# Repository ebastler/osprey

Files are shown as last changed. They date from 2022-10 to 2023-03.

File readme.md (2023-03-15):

# Osprey

The Osprey is a column staggered 40% wireless ergonomic keyboard. PCB and 3D-printable case are both open source (CERN OHL Permissive), and so is the software (MIT) as it is designed to run the [ZMK firmware](https://github.com/zmkfirmware/zmk).

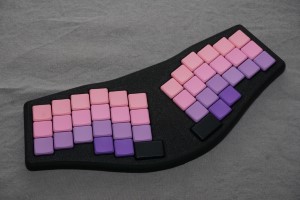
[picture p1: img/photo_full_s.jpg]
Entire board
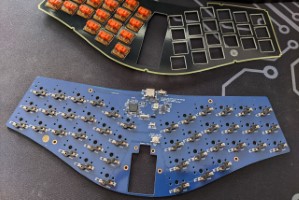
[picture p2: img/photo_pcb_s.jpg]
Entire PCB
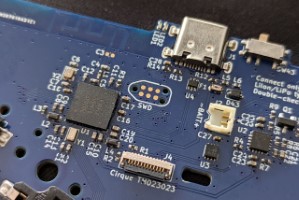
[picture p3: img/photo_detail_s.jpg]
PCB detail
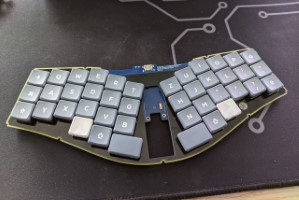
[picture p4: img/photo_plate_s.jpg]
Plate with caps and PCB
     

The board was designed to be an elegant and sleek unibody keyboard, without sacrificing typing comfort or portability. While the enclosure has raised edges to hide the keyswitches for a more refined look, it is still as slim as possible with Choc v1 switches, leading to a total thickness of about 16 mm from bottom to keycap top, if used with MBK keycaps.

The PCB is "floating" inside the case and the switches are held in-place by a 1.2 mm FR4 plate, which is sandwiched between case top and bottom half.

## Hardware
The Rev A is the first board in the Osprey family, using an nRF52840 chip, running in full DC-DC mode for highest possible battery life. A Texas Instruments BQ24075 battery management chip ensures reliable charging, while a MAX17048 fuel gauge allows for accurate battery status measurements which are communicated to your PC via Bluetooth.

The PCB is designed for Kailh Choc v1, which can be hot-swapped, and does not need any stabilizers - the largest key is 1.5u for the thumbs.

The PCB has connectors to connect either an Alps RKJXU1210006 (also known as PSP-3000 thumbstick) or a Cirque TM023023 touchpad - Both are not yet supported firmware-side and by the case design, but the PCB is ready for either.

You will also need a 502030 battery (20 x 30 x 5 mm), which usually come between 200 and 250 mAh of capacity. The board uses a JST ACH low profile connector, so you will need either a JST ACH or Molex Pico EZmate cable to crimp/solder to the battery to connect it to the PCB - please be wary of the pinout and do not connect a wrong polarity battery, as that would destroy the PCB.

It was prototyped at PCBway and turned out great. Other manufacturers should be able to make sense of the files I attached and solder these PCBs, but it is untested so order there at your own risk. 

### Files needed for ordering the PCB:

- Order in 1.6mm FR4, ENIG finish
- [Gerber Files](osprey_rev_a/fab/osprey_rev_a-GERBER.zip)
- [BOM file](osprey_rev_a/fab/osprey_rev_a_BOM.xlsx)
- [POS file](osprey_rev_a/fab/osprey_rev_a-bottom-POS.csv)

Top side  Bottom side

### Files needed for ordering the plate:

- Order in 1.2mm FR4, finish does not matter
- [Gerber Files](osprey_plate/fab/osprey_plate.zip)

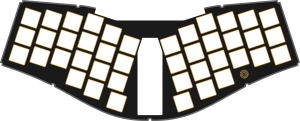
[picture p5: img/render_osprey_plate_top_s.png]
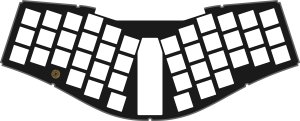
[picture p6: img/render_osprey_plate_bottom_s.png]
Bottom side
  

## Enclosure
I have attached step and 3mf files of the latest enclosure prototype - the case is still work in progress, as it lacks capability of adding thumbstick or touchpad. It is, however, tested and works fine for regular keyboard use. The enclosure is designed for [Ruthex M2 threaded inserts](https://www.ruthex.de/products/ruthex-gewindeeinsatz-m2-70-stuck-rx-m2x4-messing-gewindebuchsen) and M2x8 cylindrical head screws with flat TORX head (ISO 14580) - 9 piece each. 7 3M rubber bumpons with 7.9 mm diameter are used as feet. Other inserts, screws and bumpons may work but are untested.
- [Top enclosure, step](osprey_enclosure/osprey_enclosure_top.step)
- [Bottom enclosure, step](osprey_enclosure/osprey_enclosure_bot.step)
- [Top enclosure, 3mf](osprey_enclosure/osprey_enclosure_top.3mf)
- [Bottom enclosure, 3mf](osprey_enclosure/osprey_enclosure_bot.3mf)

Front side  Rear side

## Software
As mentioned earlier, the board is designed to run the open source ZMK firmware. My current firmware config can be found in my [ZMK config](https://github.com/ebastler/zmk-config/tree/osprey-a/config/boards/arm/osprey) repository. Since the MAX17048 needs a not-yet-merged pull request (and some manual fixes applied to it) it points towards a custom branch on a ZMK fork, not towards the official repository. This board can not (yet) be built from ZMK main branch. The current version is broken and softbricks the board!

I am using an Adafruit Bootloader, a readily compiled one can be downloaded from the [github actions in my fork of their repository](https://github.com/ebastler/Adafruit_nRF52_Bootloader/actions). This needs to be flashed with a J-Link, Black Magic Probe or modified STlink v2 using a TC2030 flashing header.

## Thanks
 - [PCBWay](https://www.pcbway.com/) for the top notch quality sponsored PCBs - couldn't have done it without you!
 - [propagandalf](https://github.com/propagandalf1) for the 3D printed cases - thank you very much!

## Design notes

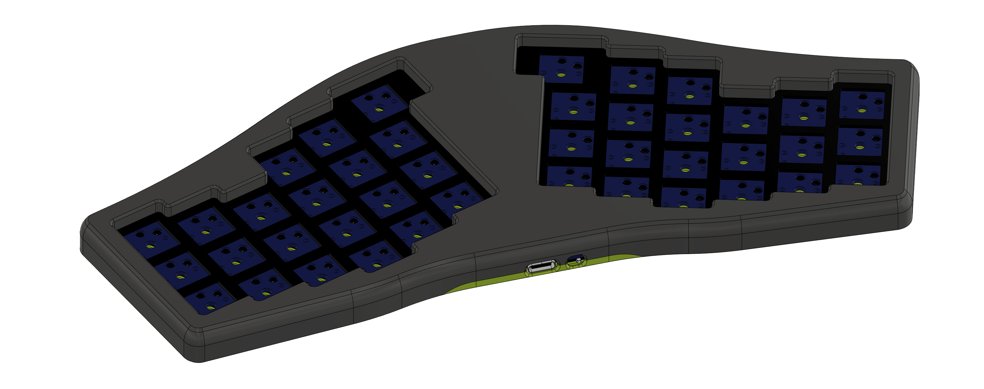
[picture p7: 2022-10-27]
img/render_osprey_case2.png

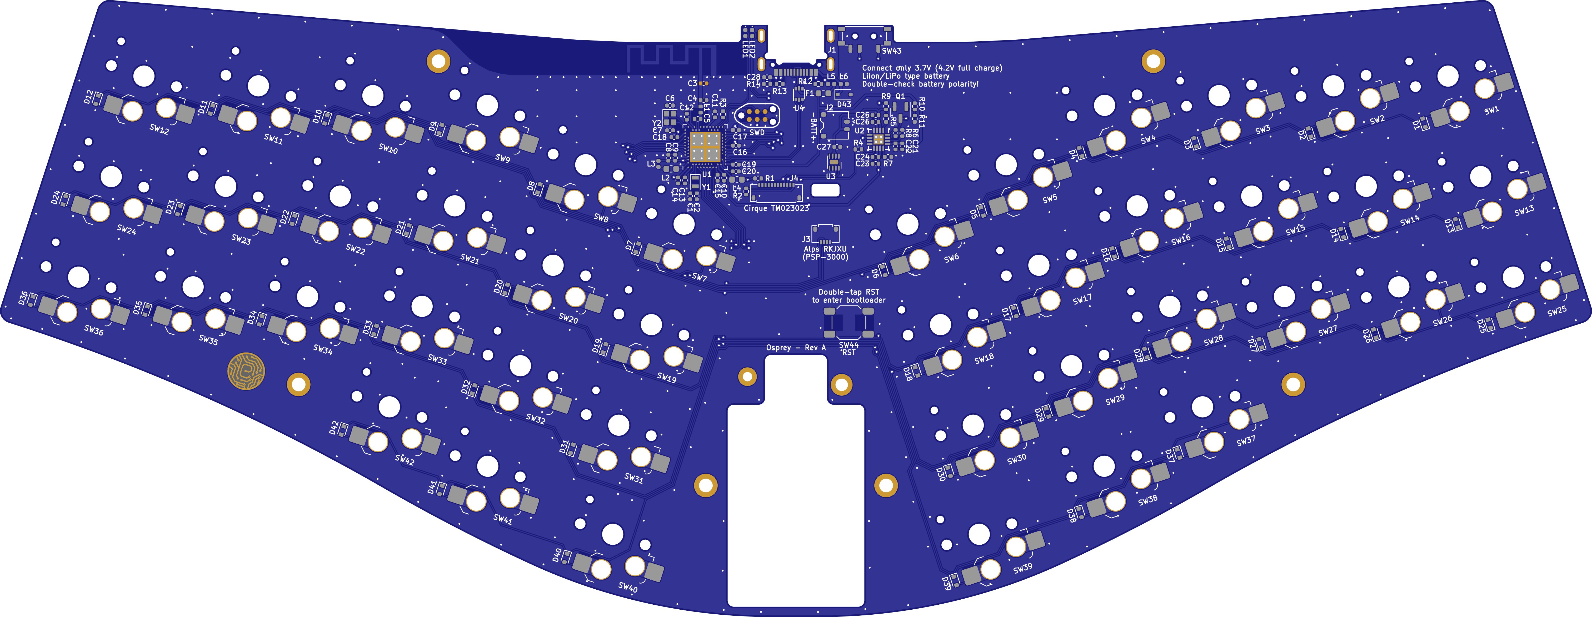
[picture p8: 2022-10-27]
img/render_osprey_rev_a_bottom.png

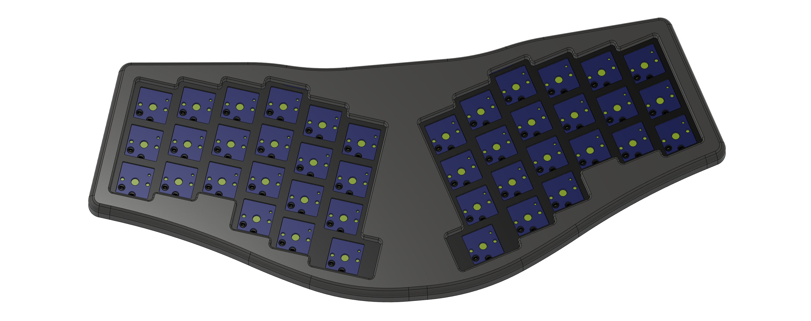
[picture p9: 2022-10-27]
img/render_osprey_case1.png

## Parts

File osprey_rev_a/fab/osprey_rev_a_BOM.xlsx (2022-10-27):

Item # | Designator | Qty | Value | Type/Description | Footprint | Manufacturer | Mfg Part # | Notes | Assembly
1 | C1, C2, C6, C7 | 4 | 12 pF | Ceramic capacitor, NP0, ±2% | 0402 |  |  | Manufacturer does not matter | SMD
2 | C3 | 0 | Not mounted | Not mounted | Not mounted |  |  | Not mounted | Not mounted
3 | C4 | 1 | 0.5 pF | Ceramic capacitor, NP0, ±10% | 0402 |  |  | Manufacturer does not matter | SMD
4 | C5 | 1 | 0.8 pF | Ceramic capacitor, NP0, ±10% | 0402 |  |  | Manufacturer does not matter | SMD
5 | C8, C14, C22, C24, C26 | 5 | 1 uF | Ceramic capacitor, X7R, ±10% | 0402 |  |  | Manufacturer does not matter | SMD
6 | C9 | 1 | 47 nF | Ceramic capacitor, X7R, ±10% | 0402 |  |  | Manufacturer does not matter | SMD
7 | C10, C15, C19, C20, C21, C23, C25 | 7 | 4.7 uF | Ceramic capacitor, X7R, ±10% | 0402 |  |  | Manufacturer does not matter | SMD
8 | C11 | 1 | 820 pF | Ceramic capacitor, NP0, ±5% | 0402 |  |  | Manufacturer does not matter | SMD
9 | C12 | 1 | 100 pF | Ceramic capacitor, NP0, ±2% | 0402 |  |  | Manufacturer does not matter | SMD
10 | C13, C16, C17, C18, C27, C28 | 6 | 100 nF | Ceramic capacitor, X7R, ±10% | 0402 |  |  | Manufacturer does not matter | SMD
11 | D1, D2, D3, D4, D5, D6, D7, D8, D9, D10, D11, D12, D13, D14, D15, D16, D17, D18, D19, D20, D21, D22, D23, D24, D25, D26, D27, D28, D29, D30, D31, D32, D33, D34, D35, D36, D37, D38, D39, D40, D41, D42 | 42 | 1N4148WT | Switching diode | SOD-523 |  |  | Manufacturer does not matter | SMD
12 | D43 | 1 | BSD3C051V | Bidirectional 5V TVS | SOD-323 | BORN | BSD3C051V | Can be replaced with same-value and footprint model if easier/cheaper to source | SMD
13 | F1 | 1 | 500mA | SMD Fuse, 6V 500 mA, self-resettable, fast-blow | 0603 | Bourns | MF-FSMF050X-2 | Can be replaced with same-value and footprint model if easier/cheaper to source | SMD
14 | J1 | 1 | TYPE-C-31-M-14 | SMD USB-C (USB2.0) connector | HRO_TYPE-C-31-M-14 | HRO | TYPE-C-31-M-14 |  | SMD/THT
15 | J2 | 1 | ACH_BM02B-ACHSS | 2-pin wire-to-board connector, 1.2mm pitch, 2A | ACH_BM02B-ACHSS-GAN-ETF_1x02 | JST | BM02B-ACHSS-GAN-ETF |  | SMD
16 | J3 | 1 | FH33J-4S-0.5SH | 4-pin FFC/FPC connector, 0.5mm pitch | FH33J-4S-0.5SH | Hirose | FH33J-4S-0.5SH | Both FH33J-4S-0.5SH(10) and FH33J-4S-0.5SH(99) models are viable | SMD
17 | J4 | 1 | FH33J-12S-0.5SH | 12-pin FFC/FPC connector, 0.5mm pitch | FH33J-12S-0.5SH | Hirose | FH33J-12S-0.5SH | Both FH33J-12S-0.5SH(10) and FH33J-12S-0.5SH(99) models are viable | SMD
18 | L1, | 1 | 4.7 nH | SMD Inductor, 700mA, ±0.1nH | 0402 | muRata | LQG15HS4N7B02D | Can be replaced with same-value and footprint model if easier/cheaper to source | SMD
19 | L2, L4 | 2 | 10 uH | SMD Inductor, 80mA, ±10% | 0603 | Taiyo Yuden | LBMF1608T100K | Can be replaced with same-value and footprint model if easier/cheaper to source | SMD
20 | L3 | 1 | 15 nH | SMD Inductor, 450mA, ±5% | 0402 | muRata | LQG15HS15NJ02D | Can be replaced with same-value and footprint model if easier/cheaper to source | SMD
21 | L5, L6 | 2 | 120R/2A | Ferrite bead 2A 55 mOhm 120Ohm @ 100MHz | 0402 | muRata | BLM15PX121SN1D | Can be replaced with same-value and footprint model if easier/cheaper to source | SMD
22 | LED1 | 1 | blue LED | SMD LED, blue, 5mA or more max forward current | 0402 |  |  | Manufacturer does not matter | SMD
23 | LED2 | 1 | orange LED | SMD LED, orange, 5mA or more max forward current | 0402 |  |  | Manufacturer does not matter | SMD
24 | Q1 | 1 | 2N7002 | SMD MOSFET, 115 mA, n-Ch | SOT-23-3 |  |  | Manufacturer does not matter | SMD
25 | R1, R2, R5, R11 | 4 | 10 kOhm | 1/16 W SMD resistor, ±1% | 0402 |  |  | Manufacturer does not matter | SMD
26 | R3, R4 | 2 | 1 kOhm | 1/16 W SMD resistor, ±1% | 0402 |  |  | Manufacturer does not matter | SMD
27 | R6 | 1 | 47 kOhm | 1/16 W SMD resistor, ±1% | 0402 |  |  | Manufacturer does not matter | SMD
28 | R7 | 1 | 1.5 kOhm | 1/16 W SMD resistor, ±1% | 0402 |  |  | Manufacturer does not matter | SMD
29 | R8 | 1 | 3.9 kOhm | 1/16 W SMD resistor, ±1% | 0402 |  |  | Manufacturer does not matter | SMD
30 | R9 | 1 | 100 kOhm | 1/16 W SMD resistor, ±1% | 0402 |  |  | Manufacturer does not matter | SMD
31 | R10 | 1 | 100 Ohm | 1/16 W SMD resistor, ±1% | 0402 |  |  | Manufacturer does not matter | SMD
32 | R12, R13 | 2 | 5.1 kOhm | 1/16 W SMD resistor, ±1% | 0402 |  |  | Manufacturer does not matter | SMD
33 | R14 | 1 | 1 MOhm | 1/16 W SMD resistor, ±1% | 0402 |  |  | Manufacturer does not matter | SMD
34 | SW1, SW2, SW3, SW4, SW5, SW6, SW7, SW8, SW9, SW10, SW11, SW12, SW13, SW14, SW15, SW16, SW17, SW18, SW19, SW20, SW21, SW22, SW23, SW24, SW25, SW26, SW27, SW28, SW29, SW30, SW31, SW32, SW33, SW34, SW35, SW36, SW37, SW38, SW41, SW42, SW39, SW40, SW41, SW42 | 42 | CPG135001S30 | Hotswap socket for Kailh Choc type keyboard switches | CPG135001S30 | Kailh | CPG135001S30 |  | SMD
35 | SW43 | 1 | MSK12C02 | SMD SPDT switch, 50 mA | MSK12C02 | SHOU HAN | MSK12C02 | Manufacturer does not matter, multiple manufcaturers offer this part | SMD
36 | SW44 | 1 | SKQGAKE010 | ALPS SPST-SKQG | SKQGAKE010 | Alps Alpine | SKQGAKE010 | All SKQGA*E010 models are acceptable as substitutes if cheaper/easier available | SMD
37 | U1 | 1 | nRF52840 | Bluetooth Low Energy capable Microcontroller | Nordic_AQFN-73-1EP_7x7mm_P0.5mm | Nordic Semiconductor | nRF52840-QIAA |  | SMD
38 | U2 | 1 | BQ24075 | Battery charging IC with PowerPath capability | VQFN-16-1EP_3x3mm_P0.5mm_EP1.6x1.6mm | Texas Instruments | BQ24075RGTR | BQ24075RGTT and BQ24075RGTR can be used according to price and availability | SMD
39 | U3 | 1 | MAX17048 | Fuel Gauge IC | DFN-8-1EP_2x2mm_P0.5mm_EP0.7x1.3mm | Maxim Integrated | MAX17048G+ |  | SMD
40 | U4 | 1 | USBLC6-2P6 | Low capacitance ESD protection | Package_TO_SOT_SMD:SOT-666 | STMicroelectronics | USBLC6-2P6 | Other manufacturers are acceptable as substitute, multiple manufcaturers offer this part | SMD
41 | Y1 | 1 | 32.768 KHz | XTAL SMD 2012 (2 pin), 32.768kHz, 9pF, ±20ppm | Crystal_SMD_2012-2Pin_2.0x1.2mm | Seiko Instruments | SC20S-9.0PF20PPM | Can be replaced with same-value and footprint model if easier/cheaper to source | SMD
42 | Y2 | 1 | 32 MHz | XTAL SMD 2016 (4 pin), 32MHz, Cl=8pF, ±10ppm | Crystal_SMD_2016-4Pin_2.0x1.6mm | Murata | XRCGB32M000F1H01R0 | Can be replaced with same-value and footprint model if easier/cheaper to source | SMD

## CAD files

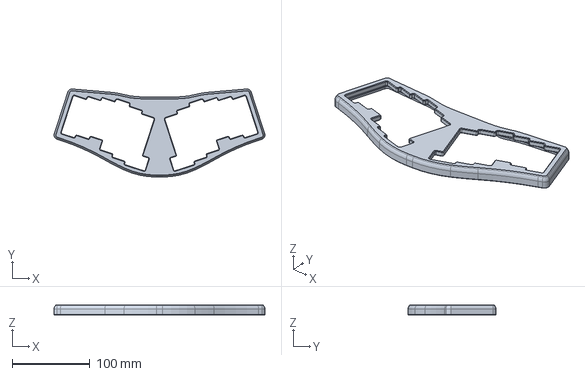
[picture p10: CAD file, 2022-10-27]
osprey_enclosure/osprey_enclosure_top.step
271.9 x 113.5 x 13.1 mm

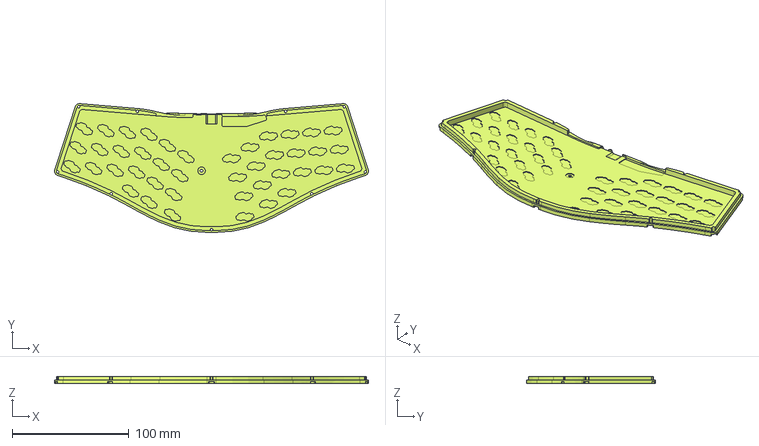
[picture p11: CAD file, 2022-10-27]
osprey_enclosure/osprey_enclosure_bot.step
268.6 x 110.2 x 6.40 mm

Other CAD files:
osprey_enclosure/osprey_enclosure_bot.3mf
osprey_enclosure/osprey_enclosure_top.3mf

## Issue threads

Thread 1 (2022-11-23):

Screws and Nuts

F1hone, 2022-11-23:
Hi, your project is really impressive,
I would also like to try to do the same
Could you please post more pictures of the screws and nuts used in the keyboard?
It would be great if there were models with screws and nuts
thank you very much

ebastler, 2022-11-25:
Hi, I added the specs for threaded inserts and screws to the readme just now!

Closed 2022-12-03.

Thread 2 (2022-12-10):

PCBWay sponsored - Easy ordering option?

Snowflake6, 2022-12-10:
Given that PCBWay sponsored this, is there any way that we could place an order for "what you did" with them, as they already have the setup for building them?  ie. to avoid paying as much of the setup and validation charges that might normally apply elsewhere?

ebastler, 2022-12-17:
Hi! To be honest, I have no idea... Doubt it though :/

Closed 2023-12-30.

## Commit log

2022-10-27 initial commit for publishing
    [osprey_enclosure_bot.3mf, osprey_enclosure_bot.step, osprey_enclosure_top.3mf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]
2022-11-25 fixed gitignore, added POS file, updated to new case proto pictures, added screws and bumpons needed to readme
    [osprey_rev_a-bottom-POS.csv]
